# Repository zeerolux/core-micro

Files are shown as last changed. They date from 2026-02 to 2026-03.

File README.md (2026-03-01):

# Zeerolux Core-Micro

A lighting controller, control surface with 5 faders and 2 encoders, a USB DMX interface, an ARTNET node, and a standalone DMX generator. The Core-Micro system consists or 4 modules; the logic processor, the control surface, the DMX interface, and the redundant USB-C power supply. These modules are designed in a way that allows them to be iterated on separetly and allow for a limitless amount of configuration. How do you use Core-Micro? It depends on how YOU need to use it. Core-Micro can be used as a midi controller for On-PC lighting softwares, it can be used in a standalone mode where it acts like an all in one system for controlling stage lighting, and eventually it will be able to run in conjuction with other Zeerolux hardware and software as either the main controller or as a programming wing. It can also be used as an ARTNET node, this means that you can connect to it over the network and output DMX out its outputs.

### Defintions:
- DMX: Digital Multiplex is an RS485 based communication standard for controlling stage lights and equipment.
- ARTNET: DMX over IP
- On-PC: A standard term used by lighting consoles to describe control systems that require a laptop or PC to operate as opposed to all processing running on console.



### Why?
I decided to take on this project after I realised how incredibly expensive lighting consoles are. Out of curiosity, I wanted to see whether I could build my own console and what price it would turn out at. Another inspiration was my experience with the Avolites Quartz which to say the least was... frustrating, so naturally, I was fresh with ideas on what not to do.



## The Hardware
Core-Micro has four PCBs; one for each module. 

### Logic PCB:


The Logic PCB does a few main things:
- Connects to PC over USB
- Processes DMX signals and distrobutes them to DMX PCB(s)
- Runs ARTNET
- Interfaces with Surface PCB
All the main processing is powered by an RP2040 and the ethernet controller is a W5500.



### Control Surface PCB


This PCB's purpose is as follows:
- To have enough buttons to comfortably program lights
- To have enough faders for basic theatre applications
- To interface with the Logic board and passthrough control to PC applications or standalone mode.
Like the Logic PCB, the Control Surface is powered by an RP2040 and sends commands to other components via UART.



### Power PCB


Why do we need a separate PCB for power? Redundancy. In a live production environment, we cannot tolerate any power cuts or flaky USB connections. Therefore, I designed a board that has two inputs that can automatically be switched between if one cuts out. This allows for:
- Usage of independant power supplies for redundancy
- Automatic switch over to battery power during power cuts or brownouts
There is also a Superviser IC on this PCB in case I want to add that functionality in the future to other modules.



### DMX Interface PCB


This simple PCB converts the PIO DMX signal into RS485 signal that can be sent to DMX fixtures. This board also has both 3-pin and 5-pin XLR to ensure you can connect to any light.



## The Software

At this current moment, the software is a minimal version designed for testing DMX and ARTNET in a standalone mode. Here is the ideal list of software features I would like to implement:
- Standalone mode
- ARTNET node mode
- Midi Mode
- Custom serial driver for control via custom software

## BOM

## Bill of Materials (BOM)

| Item | Qty | Link / Supplier | List Price  | Actual  | Location | Shipping  |
|---|-----|---|---|---|---|---|
| Surface PCB | 5 | JLCPCB | 17.90 | 190.94 | JLCPCB | 33.14 |
| Surface PCB Assembly | 2 | JLCPCB | 39.89 | — | aliexpress | — |
| Logic PCB | 5 | JLCPCB | 4.00 | — | mouser | 20.00 |
| Logic PCB Assembly | 2 | JLCPCB | 48.14 | — | beekeeb | 15.64 |
| DMX PCB | 5 | JLCPCB | 4.00 | — | — | — |
| DMX PCB Assembly | 2 | JLCPCB | 18.58 | — | — | — |
| Power PCB | 5 | JLCPCB | 2.00 | — | — | — |
| Power PCB Assembly | 2 | JLCPCB | 43.29 | — | — | — |
| Encoders | 3 | Mouser | 5.07 | 5.07 | — | — |
| Faders | 5 | Mouser | 9.60 | 9.60 | — | — |
| USB B Socket | 1 | Mouser | 0.95 | 0.95 | — | — |
| Threaded Inserts M3 | 100 | AliExpress | 5.00 | 5.00 | — | — |
| Threaded Inserts M2 | 100 | AliExpress | 5.00 | 5.00 | — | — |
| Screws M3 | 50  | AliExpress | 3.00 | 3.00 | — | — |
| Screws M2 | 50  | AliExpress | 3.00 | 3.00 | — | — |
| Key Switches | 50  | Beekeeb | 49.00 | 49.00 | — | — |
| Neutrik 3 Pin XLR | 2 | Mouser | 5.64 | 5.64 | — | — |
| Neutrik 5 Pin XLR | 2 | Mouser | 7.74 | 7.74 | — | — |
| Shipping (overall products) | — | — | 68.78 | — | — | — |
| **Total Cost** | — | — | **284.94** | — | — | — |

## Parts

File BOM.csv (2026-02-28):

Item | Quantity | Link | List Price | Actual | location | shipping cost
Surface PCB | 5 | JLCPCB | 17.9 | 190.94 | JLCPCB | 33.14
Surface PCB Assembly | 2 | JLCPCB | 39.89 |  | aliexpress
Logic PCB | 5 | JLCPCB | 4 |  | mouser | 20
Logic PCB Assembly | 2 | JLCPCB | 48.14 |  | beekeeb | 15.64
DMX PCB | 5 | JLCPCB | 4
DMX PCB Assembly | 2 | JLCPCB | 18.58
Power PCB | 5 | JLCPCB | 2
Power PCB Assembly | 2 | JLCPCB | 43.29
Encoders | 3 | https://au.mouser.com/ProductDetail/Bourns/PEC12R-4220F-S0024?qs=Zq5ylnUbLm7u%2FuPQvUoR4Q%3D%3D | 5.07 | 5.07
Faders | 5 | https://au.mouser.com/ProductDetail/Bourns/PTA6043-2015DPB103?qs=U%2FacTlguYxYM6XeKwIsltg%3D%3D | 9.6 | 9.6
USB B socket | 1 | https://au.mouser.com/ProductDetail/Harwin/M701-330442?qs=x6EjVpvqMVOIQFAB0splYQ%3D%3D | 0.95 | 0.95
Threaded inserts m3 | 100 | https://www.aliexpress.com/item/1005008897571758.html | 5 | 5
Threaded inserts m2 | 100 | https://www.aliexpress.com/item/1005008897571758.html | 5 | 5
Screws m3 | 50 | https://www.aliexpress.com/item/1005007593838226.html | 3 | 3
Screws m2 | 50 | https://www.aliexpress.com/item/1005007593838226.html | 3 | 3
Key Switches | 50 | https://shop.beekeeb.com/products/sunset-choc-key-switch | 49 | 49
Neutrix 3 pin XLR | 2 | https://au.mouser.com/ProductDetail/Neutrik/NC3FAH-0?qs=JfNPhaIww3KVRIFFDchtUA%3D%3D | 5.64 | 5.64
Neutrix 5 pin XLR | 2 | https://au.mouser.com/ProductDetail/Neutrik/NC5FAH-0?qs=6LylQoPC2St0w7oAc5hVvw%3D%3D | 7.74 | 7.74
Shipping (over all products) | n/a | n/a | 68.78
Total Cost |  |  | 284.94

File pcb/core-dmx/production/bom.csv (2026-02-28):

Designator | Footprint | Quantity | Value | LCSC Part #
_3, _2, |  | 3
J3, J4 | TerminalBlock_Xinya_XY308-2.54-2P_1x02_P2.54mm_Horizontal | 2 | Screw_Terminal_01x02
U1 | SOIC-8_3.9x4.9mm_P1.27mm | 1 | MAX485E

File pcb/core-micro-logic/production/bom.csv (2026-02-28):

Designator | Footprint | Quantity | Value | LCSC Part #
C1, C14, C5, C8 | 0402 | 4 | 1uF | C52923
C10, C9 | 0402 | 2 | 22pF | C1555
C11, C12, C17, C18, C19, C21, C22, C23, C24, C4 | 0402 | 10 | 100nF | C1525
C13 | 0402 | 1 | 10uF | C15525
C15, C16, C3 | 0402 | 3 | 100nF
C2, C6, C7 | 0402 | 3 | 1uF
C20 | 0402 | 1 | 1nF
D1 | 0201 | 1 | LED
FB1, FB2 | 0603 | 2 | FerriteBead
J1, J2, J3, J4, J5, J6 | TerminalBlock_Xinya_XY308-2.54-2P_1x02_P2.54mm_Horizontal | 6 | Screw_Terminal_01x02
J7 | USB_C_Receptacle_HRO_TYPE-C-31-M-12 | 1 | USB_C_Receptacle_USB2.0 | C165948
J9 | HANRUN_HR911105A | 1 | HR911105A
R1, R5 | 0402 | 2 | R
R10, R12, R9 | 0402 | 3 | 10k
R11, R15 | 0402 | 2 | 1k | C11702
R13, R14, R8 | 0402 | 3 | 1k
R3, R4 | 0603 | 2 | 27R | C25190
R6, R7 | 0402 | 2 | 5k1 | C25905
U1 | QFN-56-1EP_7x7mm_P0.4mm_EP3.2x3.2mm_ThermalVias | 1 | RP2040 | C2040
U2 | SOIC127P790X216-8N | 1 | W25Q128JVS | C131025
U3 | SOT-23 | 1 | XC6206PxxxMR-Regulator_Linear | C5446
U4 | LQFP-48_7x7mm_P0.5mm | 1 | W5500
U5 | SOT-23-6 | 1 | USBLC6-2SC6 | C2827654
Y1 | Crystal_SMD_3225-4Pin_3.2x2.5mm | 1 | 12MHz | C9002

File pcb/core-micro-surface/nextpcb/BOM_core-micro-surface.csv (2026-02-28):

reference | value | footprint | MPN | manufacturer | Category | SKU | price | quantity
Brd1 | SSD1306 | 128x64OLED | SSD1306-220MT | LanTu Micro | Inductors | 1020534235 | 0.30966 | 1
C1,C10,C4,C3 | 1uF | C_0402_1005Metric | 0402ZD105MAT2A | Kyocera | Capacitors | - | - | 4
C6,C5 | 22pF | C_0402_1005Metric | 0402ZA220JAT2A | Kyocera | Ceramic Capacitors | - | - | 2
C9 | 10uF | C_0402_1005Metric | AMK105CBJ106MV-F | Taiyo Yuden | Ceramic Capacitors | - | - | 1
C11,C12,C15,C14,C13,C7,C17,C16,C2,C8 | 100nF | C_0402_1005Metric | 0402YD104ZAT2A | Kyocera | Capacitors | - | - | 10
D48,D53,D49,D52,D51 | SK6812 | LED_SK6812_PLCC4_5.0x5.0mm_P3.2mm | SK6812 | OPSCO OPTOELECTRONICS | LEDs | 1023055504 | 0.09185 | 5
D50,D23,D45,D3,D28,D11,D25,D12,D14,D46,D40,D17,D44,D8,D35,D37,D26,D2,D9,D27,D34,D22,D1,D42,D32,D29,D18,D38,D33,D43,D4,D41,D7,D21,D39,D30,D20,D36,D5,D15,D47,D6,D24,D19,D16,D31,D13,D10 | 1N4148W | D_SOD-123 | 1N4148W | TK | PIN二极管 | 2500413313 | 0.0036 | 48
F1 | 500mA | Fuse_1206_3216Metric | ILB1206ER310V | Vishay | Ferrite Beads and Chips | - | - | 1
J1 | SWD | PinSocket_1x05_P2.54mm_Vertical | 640456-5 | TE Connectivity (Tyco Electronics) | Wire-to-Board Connectors | 2500330467 | 0.18468 | 1
J2 | AudioPlug2 | Jack_3.5mm_CUI_SJ-3523-SMT_Horizontal | SJ-3523-SMT | CUI | Cables and Wire | - | - | 1
J3 | USB_B | USB_B_TE_5787834_Vertical | 5787834-1 | TE Connectivity (Tyco Electronics) | DVI / HDMI Connectors | 2500417221 | 1.05392 | 1
J4 | Screw_Terminal_01x04 | TerminalBlock_Xinya_XY308-2.54-4P_1x04_P2.54mm_Horizontal | XY308-2.54-4P | XINLAIYA | Terminal Blocks | 1008509280 | 0.38994 | 1
R3,R2 | 27R | R_0603_1608Metric | RK73B1JTTD270J | KOA | Chip SMD Resistors | - | - | 2
R5,R4,R1 | 1k | R_0402_1005Metric | MCR01MRTF1001 | Rohm | Chip SMD Resistors | - | - | 3
R7,R6 | 4.7k | R_0402_1005Metric | MCR01MZPF4701 | Rohm | Chip SMD Resistors | - | - | 2
RV3,RV4,RV2,RV5,RV1 | R_Potentiometer | POT_PTA6043 | PTA6043-2010CIB503 | Bourns | Potentiometers | - | - | 5
SW21 | SW_Push | PinSocket_1x02_P2.54mm_Vertical | 87220-2 | TE Connectivity (Tyco Electronics) | Headers | - | - | 1
SW43,SW18,SW3,SW4,SW17,SW42,SW34,SW13,SW38,SW8,SW9,SW30,SW5,SW16,SW35,SW45,SW40,SW39,SW2,SW31,SW23,SW11,SW27,SW24,SW32,SW37,SW29,SW25,SW22,SW33,SW12,SW7,SW14,SW10,SW28,SW15,SW6,SW44,SW41,SW36,SW26,SW20,SW1,SW19 | SW_Push | SW_Hotswap_Kailh_Choc_V1V2_1.00u | CPG135001S30 | Kailh | Universal | - | - | 44
SW46,SW48,SW47 | RotaryEncoder_Switch | XDCR_PEC12R-4220F-S0024 | PEC12R-4220F-S0024 | Bourns | Encoders | 1028163618 | 1.81583 | 3
U1 | RP2040 | QFN-56-1EP_7x7mm_P0.4mm_EP3.2x3.2mm | RP2040 | Raspberry Pi | Microcontrollers | 2500395072 | 0.89857 | 1
U2 | W25Q128JVS | SOIC127P790X216-8N | 25YD80-R | Vishay | Capacitors | - | - | 1
U3 | XC6206PxxxMR-Regulator_Linear | SOT-23 | MCP73833-AMI/UN | Microchip Technology | Battery Management | - | - | 1
U4 | USBLC6-2SC6 | SOT-23-6 | USBLC6-2SC6 | STMicroelectronics | TVS Diodes | 2500337959 | 0.02748 | 1
U5 | ADS1115IDGS | TSSOP-10_3x3mm_P0.5mm | ADS1115IDGST | Texas Instruments (TI) | Latches and Flip Flops | 2300141696 | 6.39041 | 1
Y1 | 12MHz | Crystal_SMD_3225-4Pin_3.2x2.5mm | AWSCR-12.00CV-T | Abracon | Resonators | 1039126278 | 0.27244 | 1

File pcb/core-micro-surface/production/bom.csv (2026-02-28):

Designator | Footprint | Quantity | Value | LCSC Part #
_6, _5, _4, _3, _2, |  | 6
BRD1 | 128x64OLED | 1 | SSD1306
C1, C10, C3, C4 | 0402 | 4 | 1uF | C52923
C11, C12, C13, C14, C15, C16, C17, C2, C7, C8 | 0402 | 10 | 100nF | C1525
C5, C6 | 0402 | 2 | 22pF | C1555
C9 | 0402 | 1 | 10uF | C15525
D1, D10, D11, D12, D13, D14, D15, D16, D17, D18, D19, D2, D20, D21, D22, D23, D24, D25, D26, D27, D28, D29, D3, D30, D31, D32, D33, D34, D35, D36, D37, D38, D39, D4, D40, D41, D42, D43, D44, D45, D46, D47, D5, D50, D6, D7, D8, D9 | D_SOD-123 | 48 | 1N4148W
D48, D49, D51, D52, D53 | LED_SK6812_PLCC4_5.0x5.0mm_P3.2mm | 5 | SK6812
F1 | 1206 | 1 | 500mA | C70076
J2 | Jack_3.5mm_CUI_SJ-3523-SMT_Horizontal | 1 | AudioPlug2
J3 | USB_B_TE_5787834_Vertical | 1 | USB_B
J4 | TerminalBlock_Xinya_XY308-2.54-4P_1x04_P2.54mm_Horizontal | 1 | Screw_Terminal_01x04
R1, R4, R5 | 0402 | 3 | 1k | C11702
R2, R3 | 0603 | 2 | 27R | C25190
R6, R7 | 0402 | 2 | 4.7k
RV1, RV2, RV3, RV4, RV5 | POT_PTA6043 | 5 | R_Potentiometer
SW1, SW10, SW11, SW12, SW13, SW14, SW15, SW16, SW17, SW18, SW19, SW2, SW20, SW22, SW23, SW24, SW25, SW26, SW27, SW28, SW29, SW3, SW30, SW31, SW32, SW33, SW34, SW35, SW36, SW37, SW38, SW39, SW4, SW40, SW41, SW42, SW43, SW44, SW45, SW5, SW6, SW7, SW8, SW9 | SW_Kailh_Choc_V1_1.00u | 44 | SW_Push
SW46, SW47, SW48 | XDCR_PEC12R-4220F-S0024 | 3 | RotaryEncoder_Switch
U1 | QFN-56-1EP_7x7mm_P0.4mm_EP3.2x3.2mm | 1 | RP2040 | C2040
U2 | SOIC127P790X216-8N | 1 | W25Q128JVS | C131025
U3 | SOT-23 | 1 | XC6206PxxxMR-Regulator_Linear | C5446
U4 | SOT-23-6 | 1 | USBLC6-2SC6 | C2827654
U5 | TSSOP-10_3x3mm_P0.5mm | 1 | ADS1115IDGS
Y1 | Crystal_SMD_3225-4Pin_3.2x2.5mm | 1 | 12MHz | C9002

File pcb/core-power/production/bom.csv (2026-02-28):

Designator | Footprint | Quantity | Value | LCSC Part #
 |  | 1
C1 | 0603 | 1 | 22nF
C2, C3 | 0603 | 2 | 10uF
C4 | 0603 | 1 | 22uF
C5, C6 | 0603 | 2 | 100nF
J1, J2 | HRO_TYPE-C-31-M-12 | 2 | USB_C_Receptacle_USB2.0_16P
J3 | TerminalBlock_Xinya_XY308-2.54-5P_1x05_P2.54mm_Horizontal | 1 | Screw_Terminal_01x05
R1, R2, R3 | RES_VISHAY_WSLP2512_C_VIS | 3 | WSLP2512R0100FEA
R5 | 0402 | 1 | 5.5k
U1, U2, U3 | VSSOP-10_3x3mm_P0.5mm | 3 | INA226
U4, U5 | Texas_X2QFN-12_1.6x1.6mm_P0.4mm | 2 | TUSB320
U6 | SOIC8-N_MC_MCH | 1 | MCP130T-315I/SN
U7 | IC_TPS2121RUXR | 1 | TPS2121RUXR

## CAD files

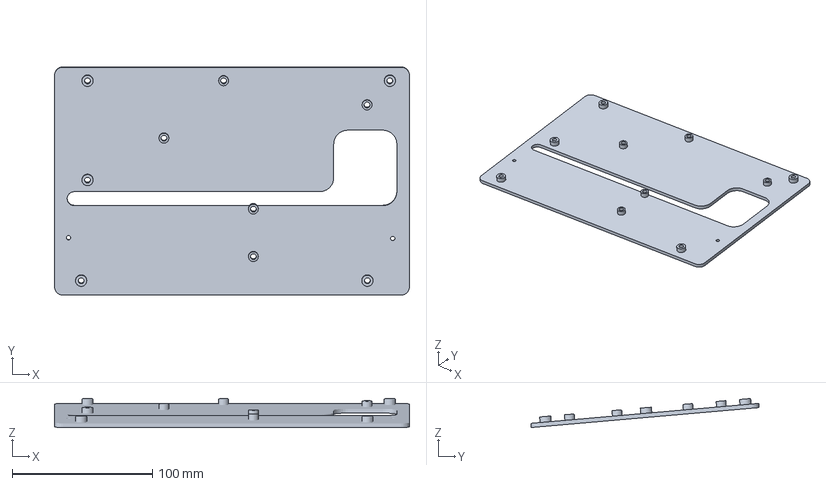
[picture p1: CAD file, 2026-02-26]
cad/Top.3mf
253.0 x 162.6 x 20.7 mm

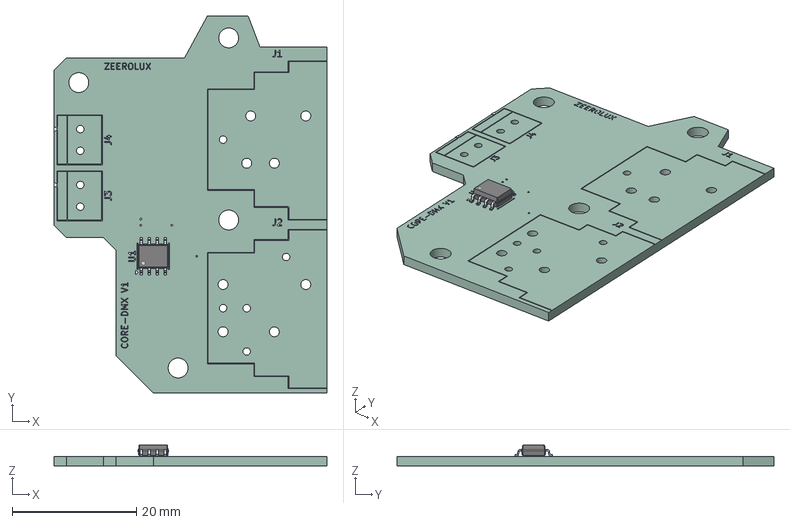
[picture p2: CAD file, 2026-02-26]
pcb/core-dmx/core-dmx.step
44.0 x 60.7 x 3.34 mm
SOIC-8_3.9x4.9mm_P1.27mm
core-dmx_silkscreen
core-dmx_PCB

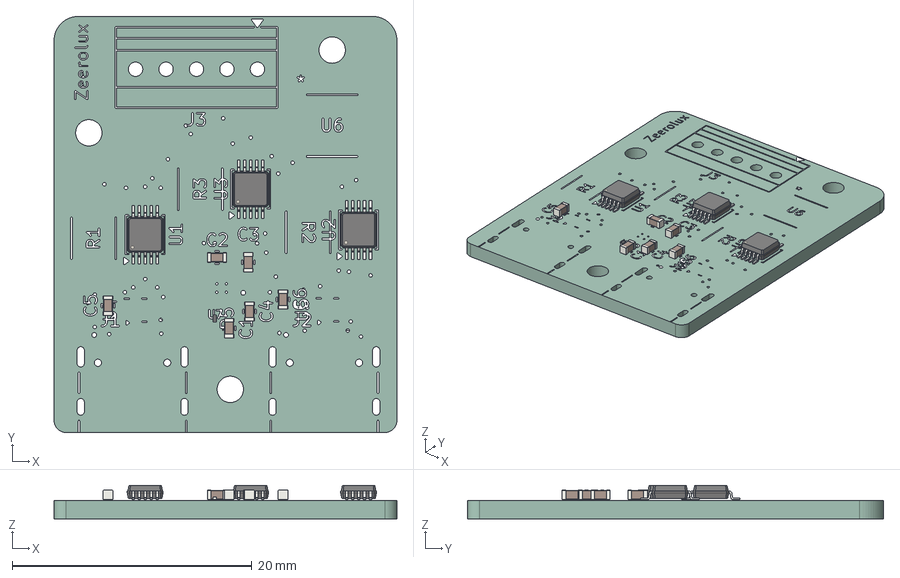
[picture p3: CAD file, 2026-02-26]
pcb/core-power/core-power.step
28.6 x 34.7 x 2.87 mm
C_0603_1608Metric x 6
VSSOP-10_3x3mm_P0.5mm x 3
R_0201_0603Metric
core-power_silkscreen x 2
core-power_PCB

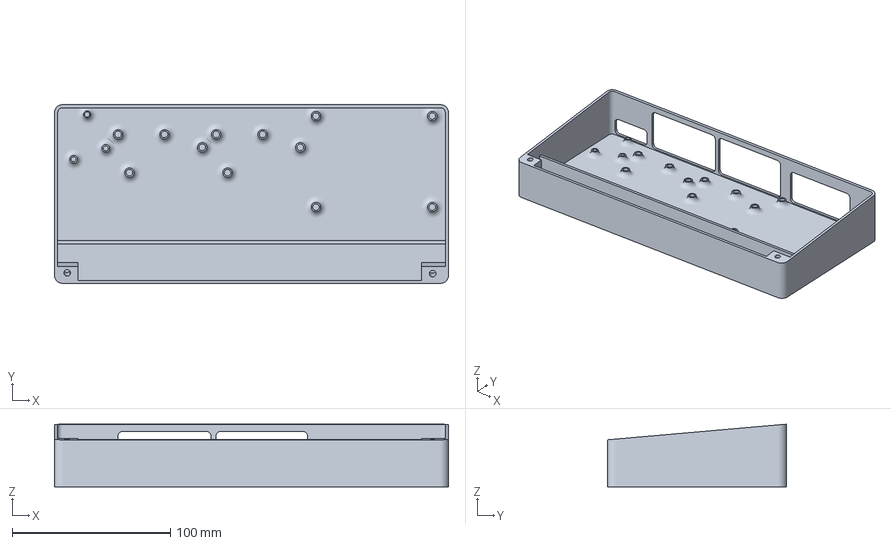
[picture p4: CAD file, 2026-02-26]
cad/Base.3mf
249.0 x 113.0 x 39.6 mm

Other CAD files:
cad/Base.f3d
cad/Top.f3d

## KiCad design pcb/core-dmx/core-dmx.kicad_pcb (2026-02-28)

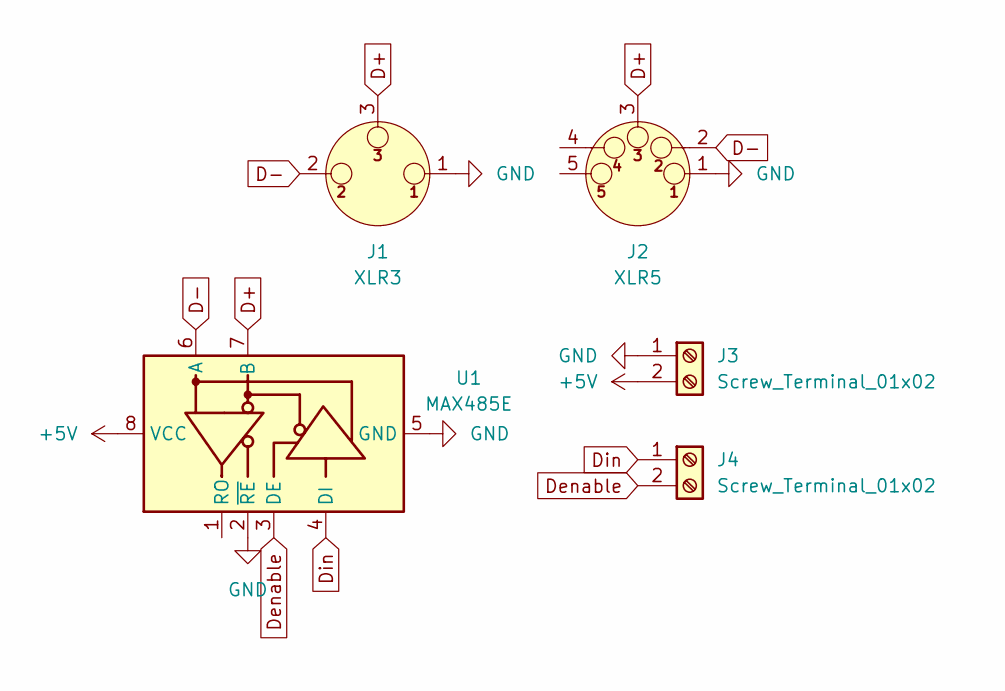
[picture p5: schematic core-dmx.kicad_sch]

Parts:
J1: XLR3; Jack_XLR_Neutrik_NC3FAH-0_Horizontal
J2: XLR5; Jack_XLR_Neutrik_NC5FAH-0_Horizontal
J3, J4: Screw_Terminal_01x02; TerminalBlock_Xinya_XY308-2.54-2P_1x02_P2.54mm_Horizontal
U1: MAX485E; SOIC-8_3.9x4.9mm_P1.27mm

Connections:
+5V: J3.2, U1.8 (VCC)
D+: J1.3, J2.3, U1.7 (B)
D-: J1.2, J2.2, U1.6 (A)
Denable: J4.2, U1.3 (DE)
Din: J4.1, U1.4 (DI)
GND: J1.1, J2.1, J3.1, U1.2 (~RE), U1.5 (GND)

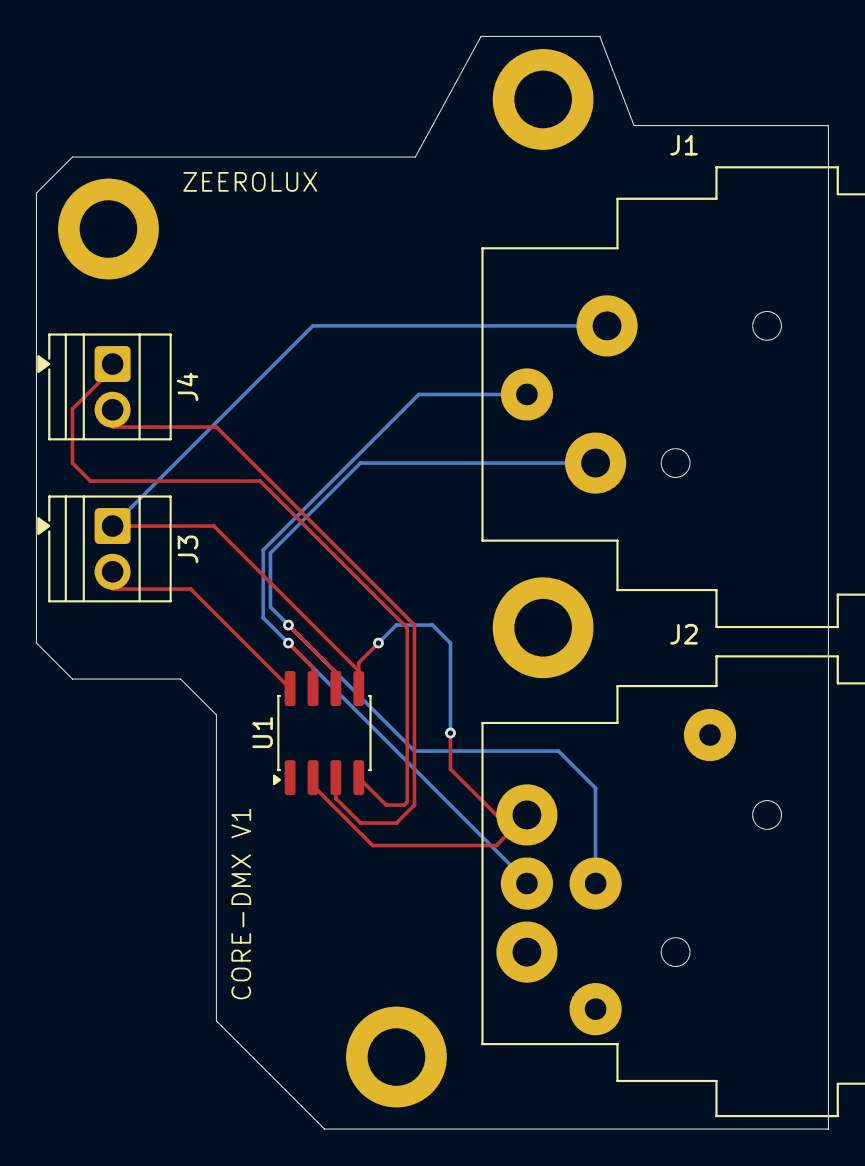
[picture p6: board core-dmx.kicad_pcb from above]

Board: 2 copper layers, 44.0 x 60.7 mm, 5 parts (0 on the bottom side), 6 nets.

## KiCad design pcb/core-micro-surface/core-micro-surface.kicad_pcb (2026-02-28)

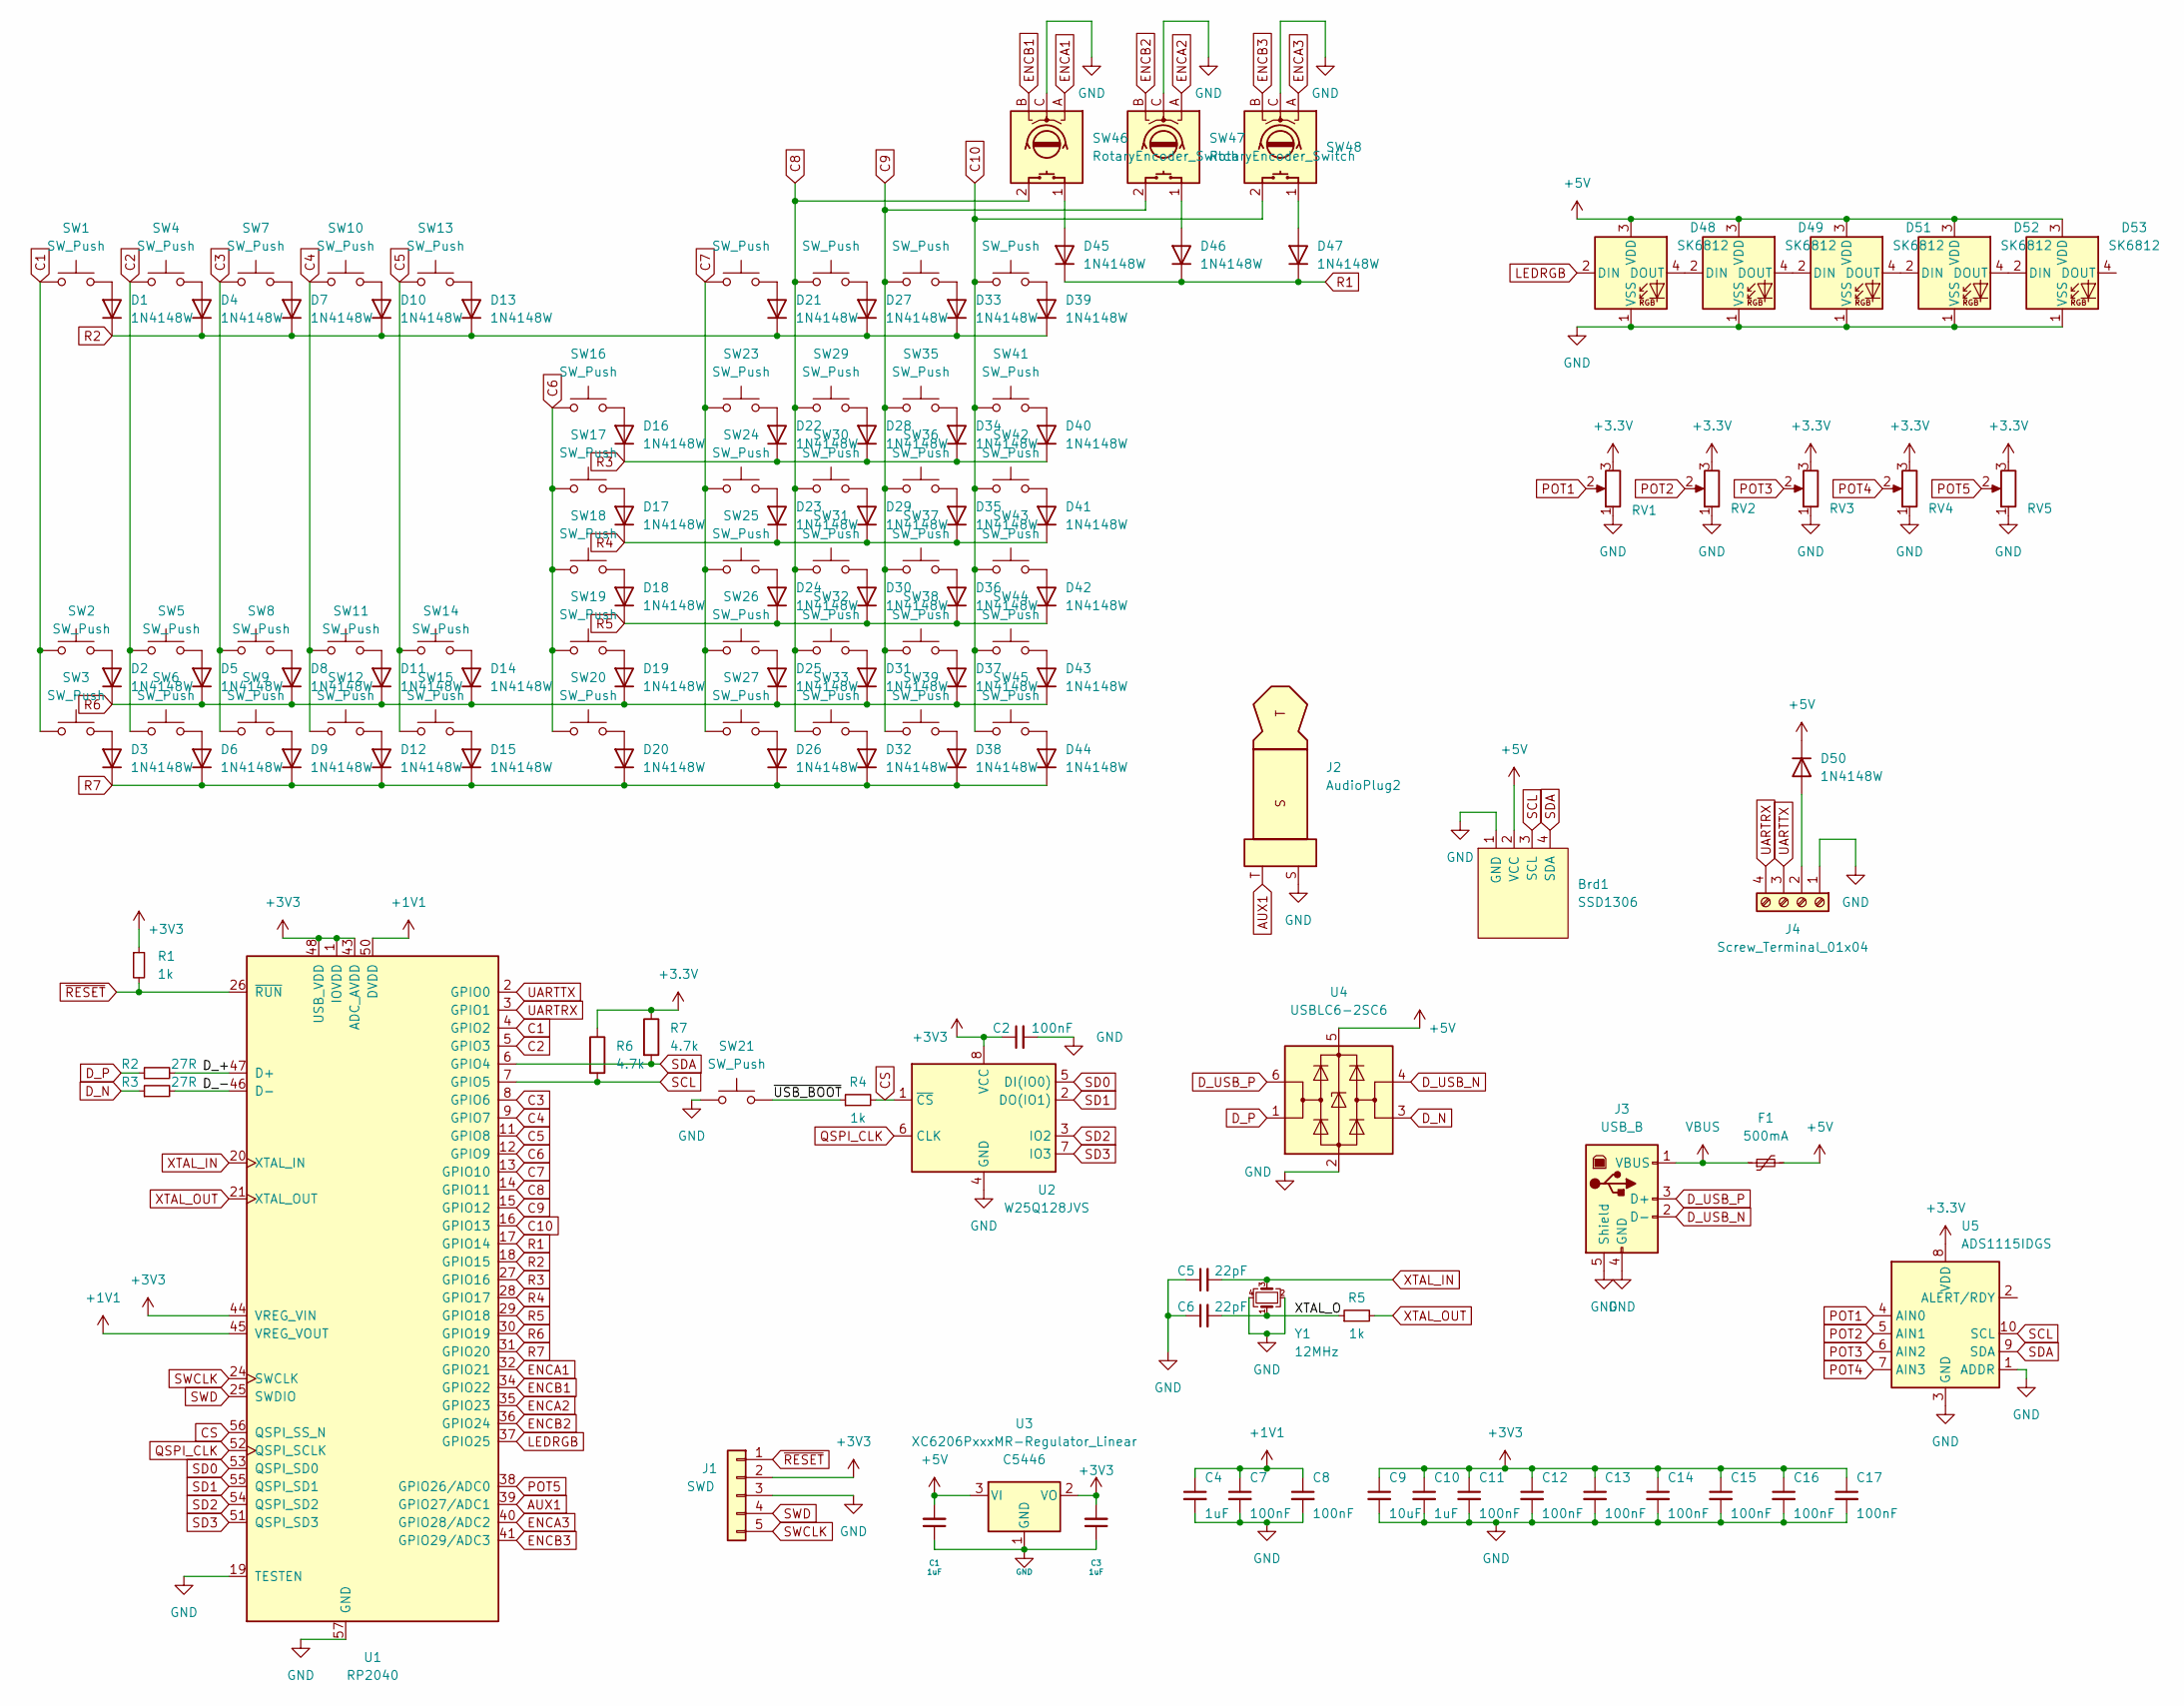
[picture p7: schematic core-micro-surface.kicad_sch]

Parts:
Brd1: SSD1306; 128x64OLED
C1, C3, C4, C10: 1uF; C_0402_1005Metric; LCSC C52923
C2, C7, C8, C11, C12, C13, C14, C15, C16, C17: 100nF; C_0402_1005Metric; LCSC C1525
C5, C6: 22pF; C_0402_1005Metric; LCSC C1555
C9: 10uF; C_0402_1005Metric; LCSC C15525
D1, D2, D3, D4, D5, D6, D7, D8, D9, D10, D11, D12, D13, D14, D15, D16, D17, D18, D19, D20, D21, D22, D23, D24, D25, D26, D27, D28, D29, D30, D31, D32, D33, D34, D35, D36, D37, D38, D39, D40, D41, D42, D43, D44, D45, D46, D47, D50: 1N4148W; D_SOD-123
D48, D49, D51, D52, D53: SK6812; LED_SK6812_PLCC4_5.0x5.0mm_P3.2mm
F1: 500mA; Fuse_1206_3216Metric; LCSC C70076
J1: SWD; PinSocket_1x05_P2.54mm_Vertical
J2: AudioPlug2; Jack_3.5mm_CUI_SJ-3523-SMT_Horizontal
J3: USB_B; USB_B_TE_5787834_Vertical
J4: Screw_Terminal_01x04; TerminalBlock_Xinya_XY308-2.54-4P_1x04_P2.54mm_Horizontal
R1, R4, R5: 1k; R_0402_1005Metric; LCSC C11702
R2, R3: 27R; R_0603_1608Metric; LCSC C25190
R6, R7: 4.7k; R_0402_1005Metric
RV1, RV2, RV3, RV4, RV5: R_Potentiometer; POT_PTA6043
SW1, SW2, SW3, SW4, SW5, SW6, SW7, SW8, SW9, SW10, SW11, SW12, SW13, SW14, SW15, SW16, SW17, SW18, SW19, SW20, SW22, SW23, SW24, SW25, SW26, SW27, SW28, SW29, SW30, SW31, SW32, SW33, SW34, SW35, SW36, SW37, SW38, SW39, SW40, SW41, SW42, SW43, SW44, SW45: SW_Push; SW_Hotswap_Kailh_Choc_V1V2_1.00u
SW21: SW_Push; PinSocket_1x02_P2.54mm_Vertical
SW46, SW47, SW48: RotaryEncoder_Switch; XDCR_PEC12R-4220F-S0024
U1: RP2040; QFN-56-1EP_7x7mm_P0.4mm_EP3.2x3.2mm; LCSC C2040
U2: W25Q128JVS; SOIC127P790X216-8N; LCSC C131025
U3: XC6206PxxxMR-Regulator_Linear; SOT-23; LCSC C5446
U4: USBLC6-2SC6; SOT-23-6; LCSC C2827654
U5: ADS1115IDGS; TSSOP-10_3x3mm_P0.5mm
Y1: 12MHz; Crystal_SMD_3225-4Pin_3.2x2.5mm; LCSC C9002

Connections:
+1V1: C4.1, C7.1, C8.1, U1.23 (DVDD), U1.45 (VREG_VOUT), U1.50 (DVDD)
+5V: Brd1.2 (VCC), C1.2, D48.3 (VDD), D49.3 (VDD), D50.1 (K), D51.3 (VDD), D52.3 (VDD), D53.3 (VDD), F1.2, U3.3 (VI), U4.5 (VBUS)
/D_+: R2.2, U1.47 (D+)
/D_-: R3.2, U1.46 (D-)
/XTAL_O: C6.2, R5.1, Y1.1
/~USB_BOOT: R4.1, SW21.2
AUX1: J2.T, U1.39 (GPIO27/ADC1)
C1: SW1.1, SW2.1, SW3.1, U1.4 (GPIO2)
C2: SW4.1, SW5.1, SW6.1, U1.5 (GPIO3)
C3: SW7.1, SW8.1, SW9.1, U1.8 (GPIO6)
C4: SW10.1, SW11.1, SW12.1, U1.9 (GPIO7)
C5: SW13.1, SW14.1, SW15.1, U1.11 (GPIO8)
C6: SW16.1, SW17.1, SW18.1, SW19.1, SW20.1, U1.12 (GPIO9)
C7: SW22.1, SW23.1, SW24.1, SW25.1, SW26.1, SW27.1, U1.13 (GPIO10)
C8: SW28.1, SW29.1, SW30.1, SW31.1, SW32.1, SW33.1, SW46.2 (S2), U1.14 (GPIO11)
C9: SW34.1, SW35.1, SW36.1, SW37.1, SW38.1, SW39.1, SW47.2 (2S2), U1.15 (GPIO12)
C10: SW40.1, SW41.1, SW42.1, SW43.1, SW44.1, SW45.1, SW48.2 (S2), U1.16 (GPIO13)
CS: R4.2, U1.56 (QSPI_SS_N), U2.1 (~CS)
D_N: R3.1, U4.3 (I/O2)
D_P: R2.1, U4.1 (I/O1)
D_USB_N: J3.2 (D-), U4.4 (I/O2)
D_USB_P: J3.3 (D+), U4.6 (I/O1)
ENCA1: SW46.A, U1.32 (GPIO21)
ENCA2: SW47.A, U1.35 (GPIO23)
ENCA3: SW48.A, U1.40 (GPIO28/ADC2)
ENCB1: SW46.B, U1.34 (GPIO22)
ENCB2: SW47.B, U1.36 (GPIO24)
ENCB3: SW48.B, U1.41 (GPIO29/ADC3)
GND: Brd1.1 (GND), C1.1, C2.2, C3.1, C4.2, C5.1, C6.1, C7.2, C8.2, C9.2, C10.2, C11.2, C12.2, C13.2, C14.2, C15.2, C16.2, C17.2, D48.1 (VSS), D49.1 (VSS), D51.1 (VSS), D52.1 (VSS), D53.1 (VSS), J1.3, J2.S, J3.4 (GND), J3.5 (Shield), J4.1, RV1.1, RV2.1, RV3.1, RV4.1, RV5.1, SW21.1, SW46.C, SW47.C, SW48.C, U1.19 (TESTEN), U1.57 (GND), U2.4 (GND), U3.1 (GND), U4.2 (GND), U5.1 (ADDR), U5.3 (GND), Y1.2, Y1.4
LEDRGB: D48.2 (DIN), U1.37 (GPIO25)
unnamed: D1.2 (A), SW1.2
unnamed: D2.2 (A), SW2.2
unnamed: D3.2 (A), SW3.2
unnamed: D4.2 (A), SW4.2
unnamed: D5.2 (A), SW5.2
unnamed: D6.2 (A), SW6.2
unnamed: D7.2 (A), SW7.2
unnamed: D8.2 (A), SW8.2
unnamed: D9.2 (A), SW9.2
unnamed: D10.2 (A), SW10.2
unnamed: D11.2 (A), SW11.2
unnamed: D12.2 (A), SW12.2
unnamed: D13.2 (A), SW13.2
unnamed: D14.2 (A), SW14.2
unnamed: D15.2 (A), SW15.2
unnamed: D16.2 (A), SW16.2
unnamed: D17.2 (A), SW17.2
unnamed: D18.2 (A), SW18.2
unnamed: D19.2 (A), SW19.2
unnamed: D20.2 (A), SW20.2
unnamed: D21.2 (A), SW22.2
unnamed: D22.2 (A), SW23.2
unnamed: D23.2 (A), SW24.2
unnamed: D24.2 (A), SW25.2
unnamed: D25.2 (A), SW26.2
unnamed: D26.2 (A), SW27.2
unnamed: D27.2 (A), SW28.2
unnamed: D28.2 (A), SW29.2
unnamed: D29.2 (A), SW30.2
unnamed: D30.2 (A), SW31.2
unnamed: D31.2 (A), SW32.2
unnamed: D32.2 (A), SW33.2
unnamed: D33.2 (A), SW34.2
unnamed: D34.2 (A), SW35.2
unnamed: D35.2 (A), SW36.2
unnamed: D36.2 (A), SW37.2
unnamed: D37.2 (A), SW38.2
unnamed: D38.2 (A), SW39.2
unnamed: D39.2 (A), SW40.2
unnamed: D40.2 (A), SW41.2
unnamed: D41.2 (A), SW42.2
unnamed: D42.2 (A), SW43.2
unnamed: D43.2 (A), SW44.2
unnamed: D44.2 (A), SW45.2
unnamed: D45.2 (A), SW46.1 (S1)
unnamed: D46.2 (A), SW47.1 (S1)
unnamed: D47.2 (A), SW48.1 (S1)
unnamed: D48.4 (DOUT), D49.2 (DIN)
unnamed: D49.4 (DOUT), D51.2 (DIN)
unnamed: D50.2 (A), J4.2
unnamed: D51.4 (DOUT), D52.2 (DIN)
unnamed: D52.4 (DOUT), D53.2 (DIN)
POT1: RV1.2, U5.4 (AIN0)
POT2: RV2.2, U5.5 (AIN1)
POT3: RV3.2, U5.6 (AIN2)
POT4: RV4.2, U5.7 (AIN3)
POT5: RV5.2, U1.38 (GPIO26/ADC0)
QSPI_CLK: U1.52 (QSPI_SCLK), U2.6 (CLK)
R1: D45.1 (K), D46.1 (K), D47.1 (K), U1.17 (GPIO14)
R2: D1.1 (K), D4.1 (K), D7.1 (K), D10.1 (K), D13.1 (K), D21.1 (K), D27.1 (K), D33.1 (K), D39.1 (K), U1.18 (GPIO15)
R3: D16.1 (K), D22.1 (K), D28.1 (K), D34.1 (K), D40.1 (K), U1.27 (GPIO16)
R4: D17.1 (K), D23.1 (K), D29.1 (K), D35.1 (K), D41.1 (K), U1.28 (GPIO17)
R5: D18.1 (K), D24.1 (K), D30.1 (K), D36.1 (K), D42.1 (K), U1.29 (GPIO18)
R6: D2.1 (K), D5.1 (K), D8.1 (K), D11.1 (K), D14.1 (K), D19.1 (K), D25.1 (K), D31.1 (K), D37.1 (K), D43.1 (K), U1.30 (GPIO19)
R7: D3.1 (K), D6.1 (K), D9.1 (K), D12.1 (K), D15.1 (K), D20.1 (K), D26.1 (K), D32.1 (K), D38.1 (K), D44.1 (K), U1.31 (GPIO20)
SCL: Brd1.3 (SCL), R6.2, U1.7 (GPIO5), U5.10 (SCL)
SD0: U1.53 (QSPI_SD0), U2.5 (DI(IO0))
SD1: U1.55 (QSPI_SD1), U2.2 (DO(IO1))
SD2: U1.54 (QSPI_SD2), U2.3 (IO2)
SD3: U1.51 (QSPI_SD3), U2.7 (IO3)
SDA: Brd1.4 (SDA), R7.2, U1.6 (GPIO4), U5.9 (SDA)
SWCLK: J1.5, U1.24 (SWCLK)
SWD: J1.4, U1.25 (SWDIO)
UARTRX: J4.4, U1.3 (GPIO1)
UARTTX: J4.3, U1.2 (GPIO0)
VBUS: F1.1, J3.1 (VBUS)
XTAL_IN: C5.2, U1.20 (XTAL_IN), Y1.3
XTAL_OUT: R5.2, U1.21 (XTAL_OUT)
~RESET: J1.1, R1.2, U1.26 (~RUN)

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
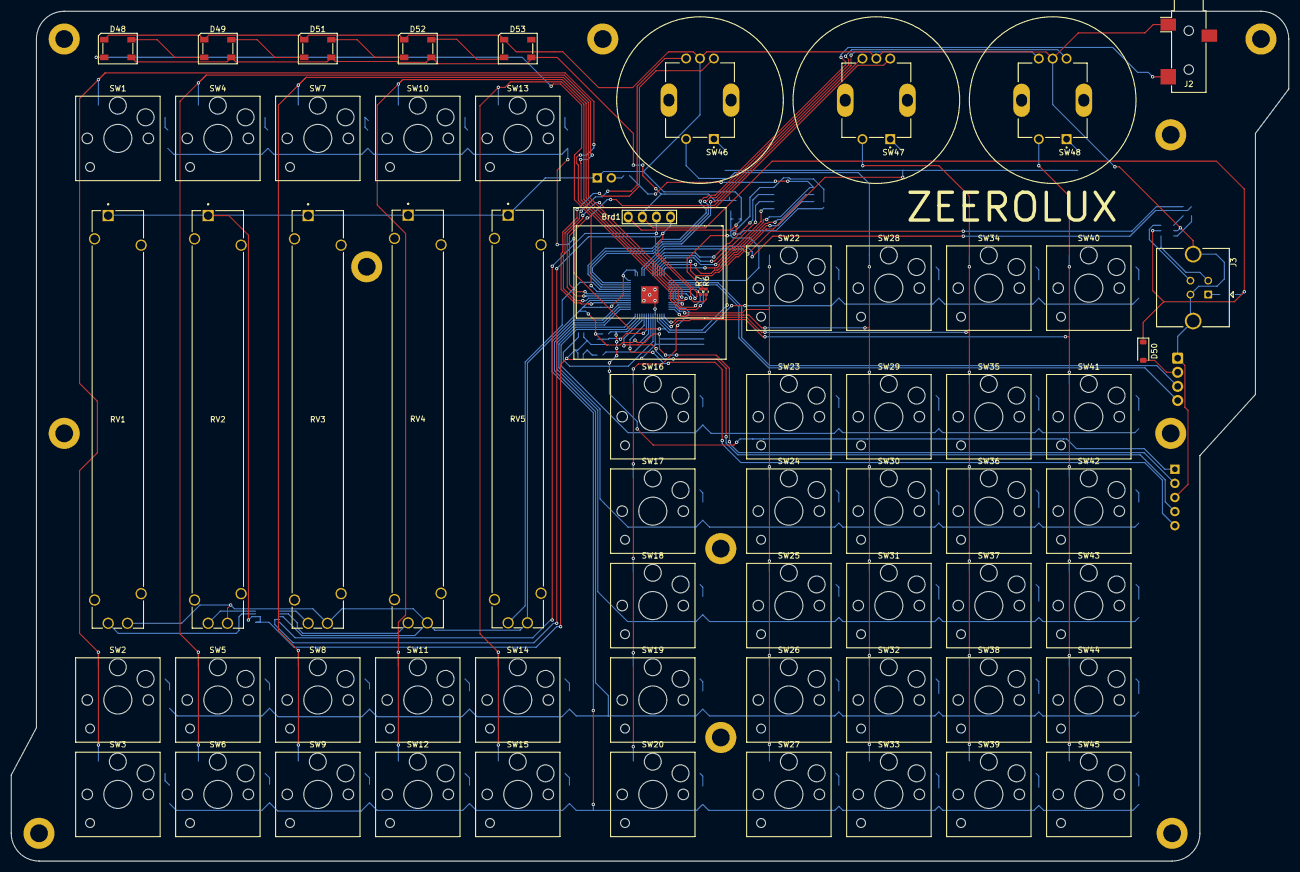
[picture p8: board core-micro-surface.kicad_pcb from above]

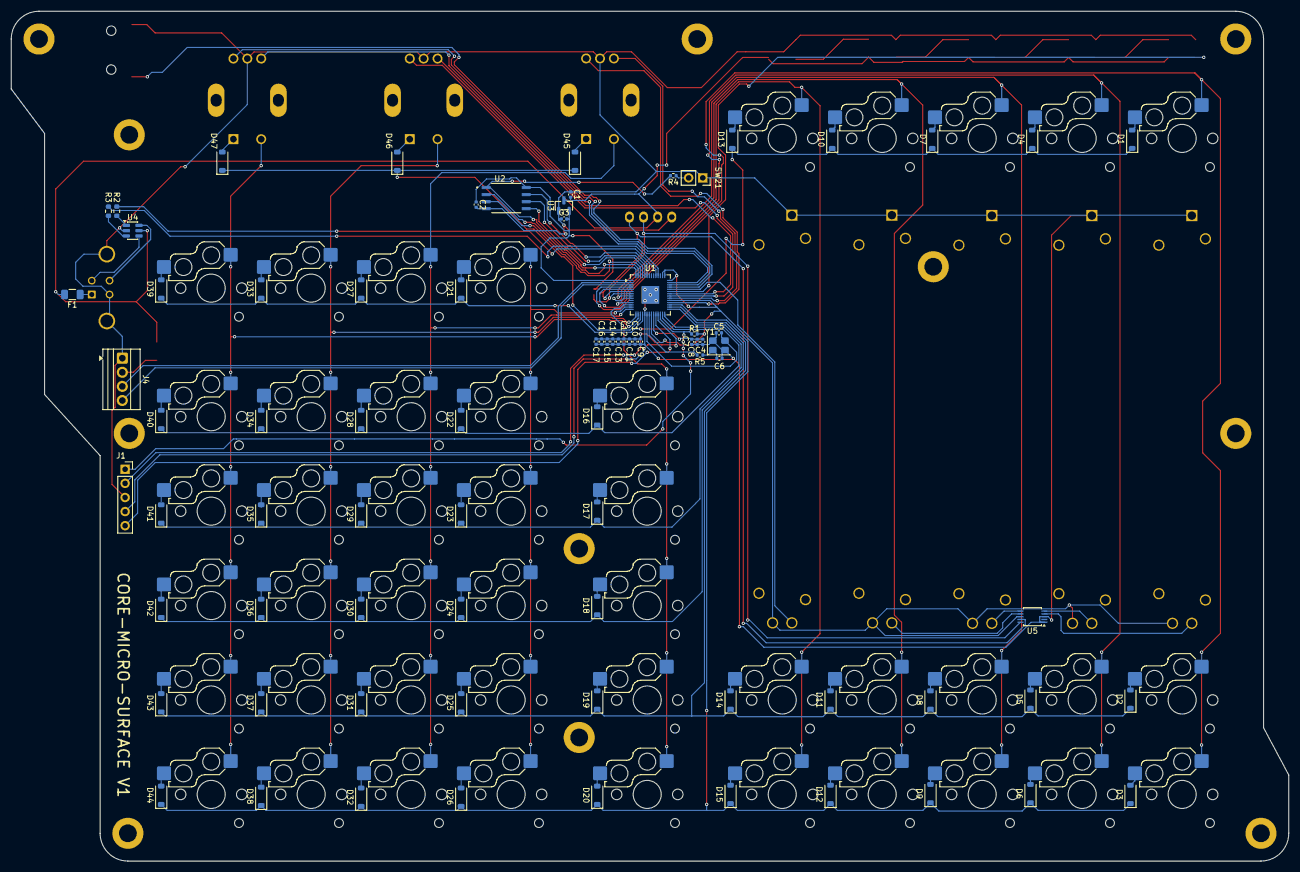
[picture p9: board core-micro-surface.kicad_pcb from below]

Board: 2 copper layers, 230.0 x 153.0 mm, 142 parts (79 on the bottom side), 111 nets.

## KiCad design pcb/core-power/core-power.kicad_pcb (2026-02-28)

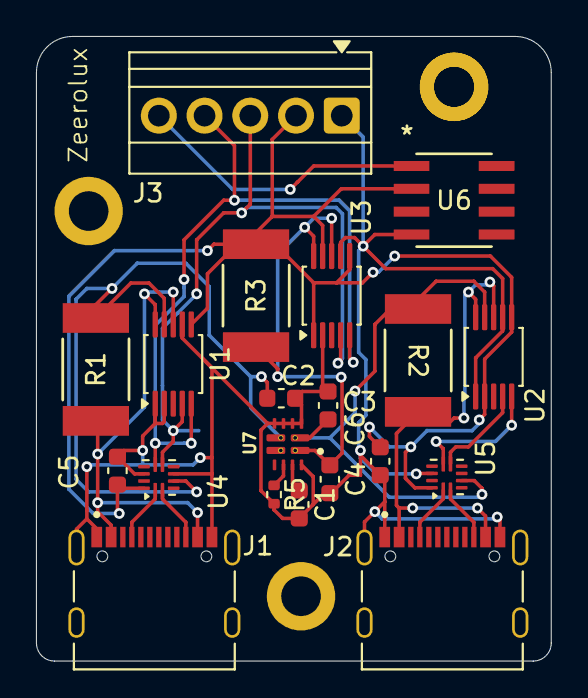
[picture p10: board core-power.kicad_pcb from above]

Board: 2 copper layers, 28.6 x 34.7 mm, 20 parts (0 on the bottom side), 16 nets.

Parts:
C1: 22nF; C_0603_1608Metric
C2, C3: 10uF; C_0603_1608Metric
C4: 22uF; C_0603_1608Metric
C5, C6: 100nF; C_0603_1608Metric
J1, J2: USB_C_Receptacle_USB2.0_16P; HRO_TYPE-C-31-M-12
J3: Screw_Terminal_01x05; TerminalBlock_Xinya_XY308-2.54-5P_1x05_P2.54mm_Horizontal
R1, R2, R3: WSLP2512R0100FEA; RES_VISHAY_WSLP2512_C_VIS
R5: 5.5k; R_0402_1005Metric
U1, U2, U3: INA226; VSSOP-10_3x3mm_P0.5mm
U4, U5: TUSB320; Texas_X2QFN-12_1.6x1.6mm_P0.4mm
U6: MCP130T-315I/SN; SOIC8-N_MC_MCH
U7: TPS2121RUXR; IC_TPS2121RUXR

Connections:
CC1-1: J1.A5 (CC1), U4.1 (CC1)
CC1-2: J2.A5 (CC1), U5.1 (CC1)
CC2-1: J1.B5 (CC2), U4.2 (CC2)
CC2-2: J2.B5 (CC2), U5.2 (CC2)
GND: C1.2, C2.2, C3.2, C4.2, C5.2, C6.2, J1.GND, J1.S1 (SHIELD), J2.A1_B12, J2.B1_A12, J2.S1 (SHIELD), J3.1, R5.2, U1.1 (A1), U1.2 (A0), U1.7 (GND), U2.1 (A1), U2.7 (GND), U3.2 (A0), U3.7 (GND), U4.5 (ADDR), U4.10 (GND), U5.10 (GND), U6.4 (VSS), U7.3 (CP2), U7.4 (OV2), U7.5 (OV1), U7.6 (PR1), U7.12 (GND)
J1V+: J1.A4_B9, R1.1, U1.8 (Vbus), U1.10 (Vin+)
J1V-: C2.1, R1.2, U1.9 (Vin-), U4.4 (VBUS_DET), U7.7 (IN1), U7.7_1 (IN1__1)
J2V+: R2.2, U2.8 (Vbus), U2.10 (Vin+)
J2V-: C3.1, R2.1, U2.9 (Vin-), U5.4 (VBUS_DET), U7.2 (IN2), U7.2_1 (IN2__1)
MUXV+: C4.1, R3.1, U3.8 (Vbus), U3.10 (Vin+), U7.1 (OUT), U7.1_1 (OUT__1), U7.8 (OUT__2), U7.8_1 (OUT__3)
MUXV-: C5.1, C6.1, J3.2, R3.2, U1.6 (VS), U2.2 (A0), U2.6 (VS), U3.1 (A1), U3.6 (VS), U3.9 (Vin-), U4.12 (VDD), U5.5 (ADDR), U5.12 (VDD), U6.2 (VDD)
unnamed: R5.1, U7.10 (ILIM)
unnamed: C1.1, U7.11 (SS)
RESET: J3.5, U6.1 (*RST)
SCL: J3.4, U1.5 (SCL), U2.5 (SCL), U3.5 (SCL), U4.8 (SCL/OUT2), U5.8 (SCL/OUT2)
SDA: J3.3, U1.4 (SDA), U2.4 (SDA), U3.4 (SDA), U4.7 (SDA/OUT1), U5.7 (SDA/OUT1)

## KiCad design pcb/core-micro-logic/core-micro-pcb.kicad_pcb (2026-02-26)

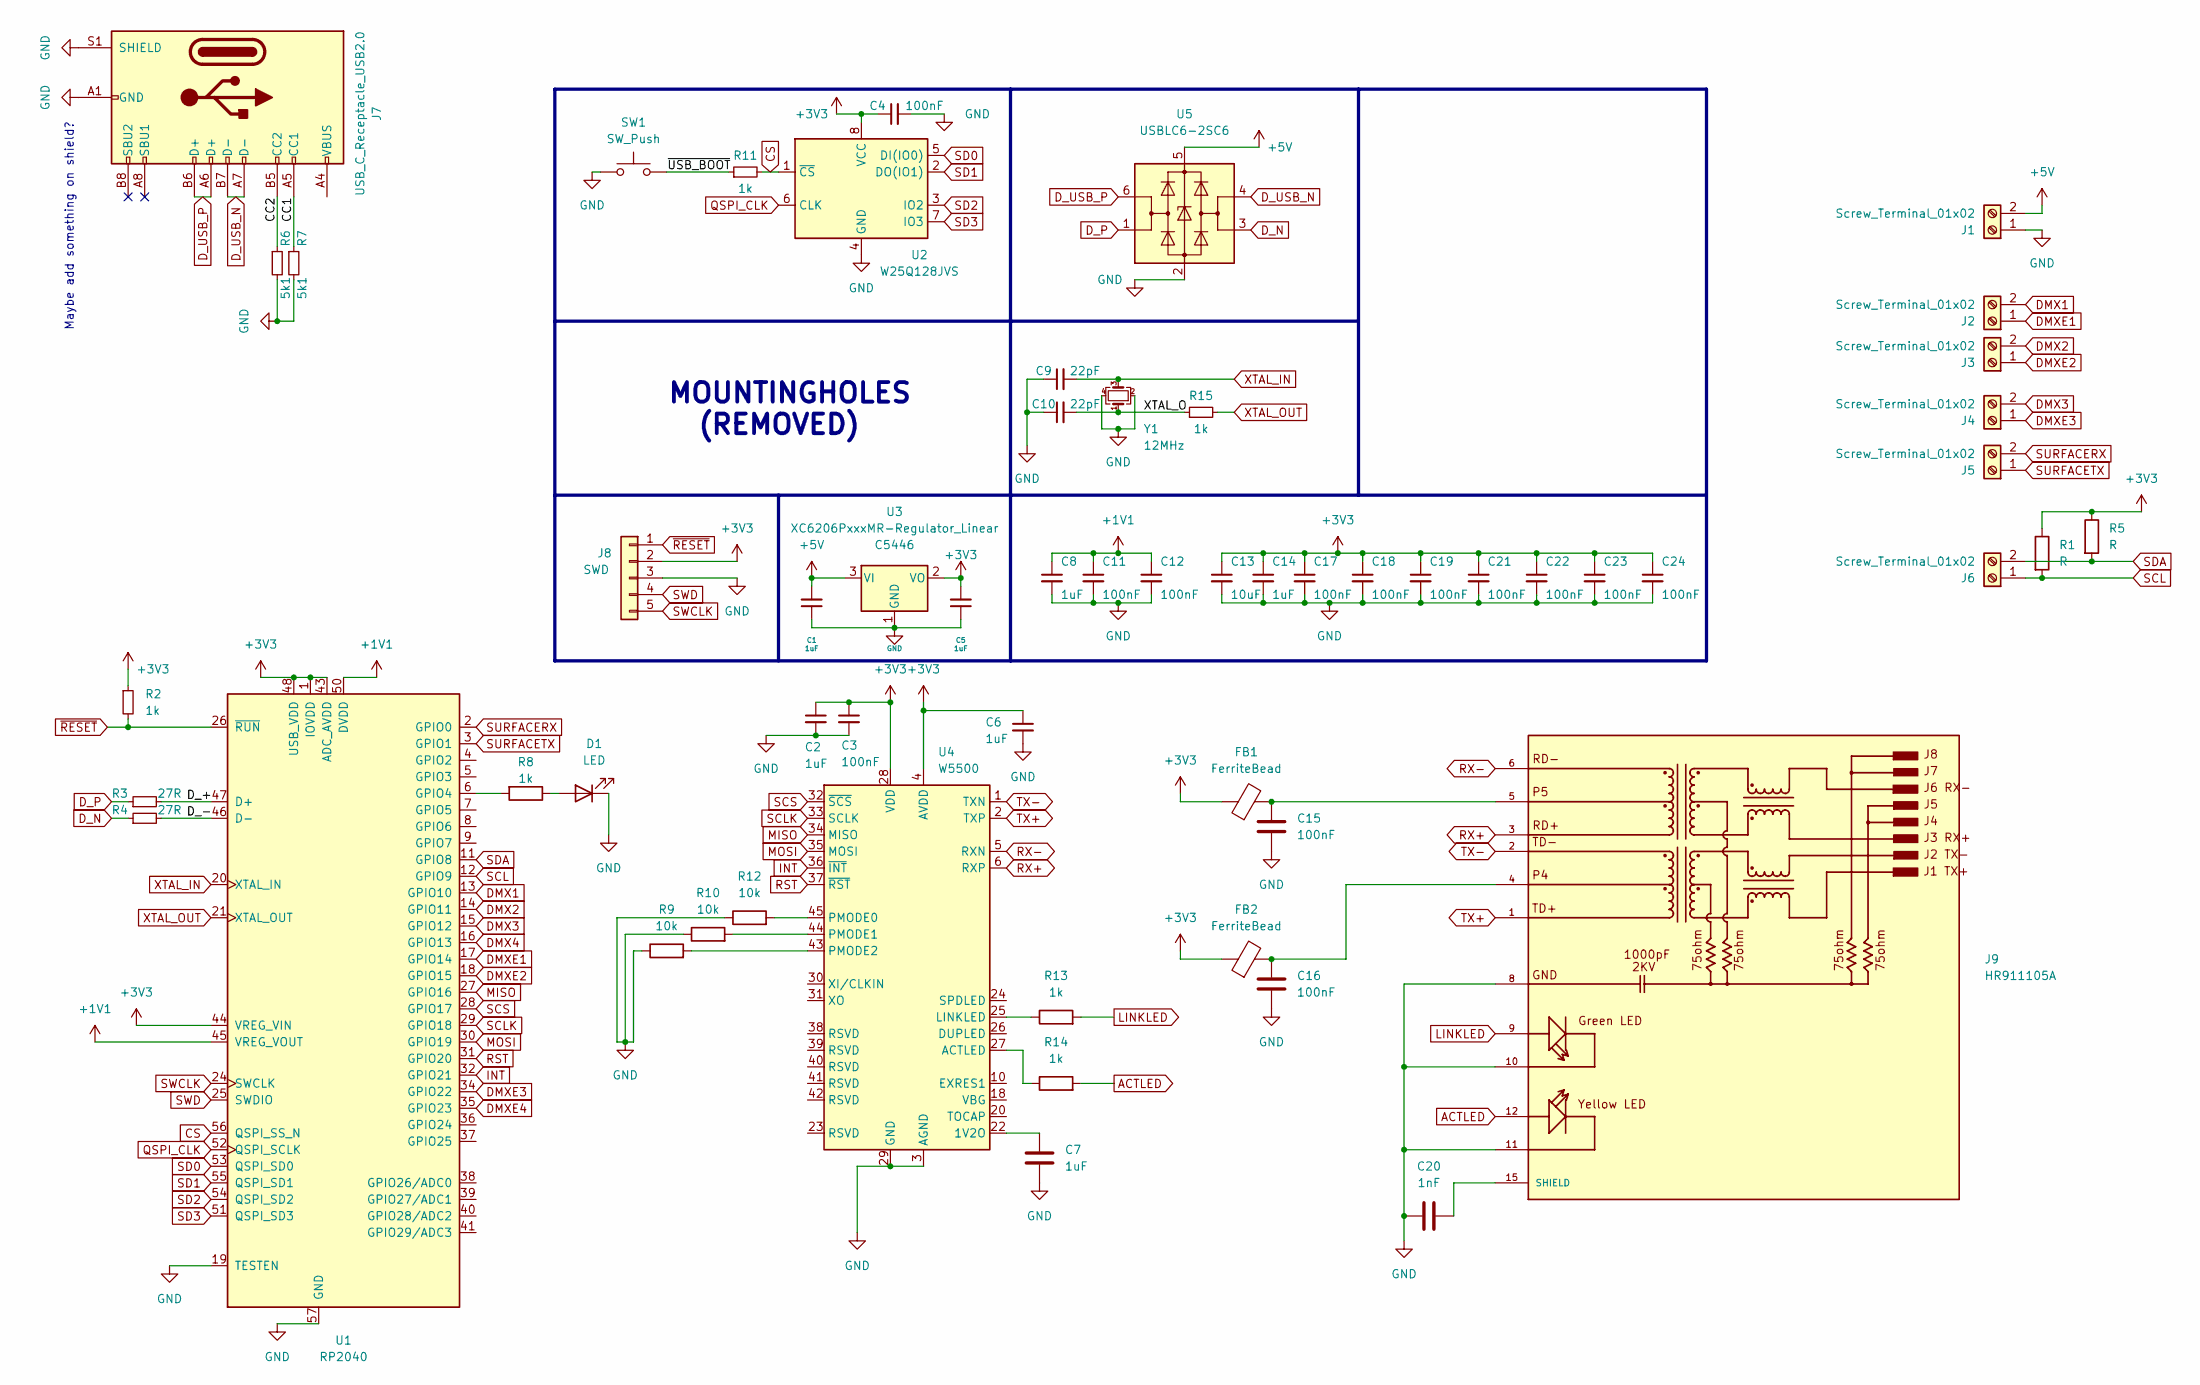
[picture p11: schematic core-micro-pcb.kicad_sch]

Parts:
C1, C5, C8, C14: 1uF; C_0402_1005Metric; LCSC C52923
C2, C6, C7: 1uF; C_0402_1005Metric
C3, C15, C16: 100nF; C_0402_1005Metric
C4, C11, C12, C17, C18, C19, C21, C22, C23, C24: 100nF; C_0402_1005Metric; LCSC C1525
C9, C10: 22pF; C_0402_1005Metric; LCSC C1555
C13: 10uF; C_0402_1005Metric; LCSC C15525
C20: 1nF; C_0402_1005Metric
D1: LED; LED_0201_0603Metric
FB1, FB2: FerriteBead; L_0603_1608Metric
J1, J2, J3, J4, J5, J6: Screw_Terminal_01x02; TerminalBlock_Xinya_XY308-2.54-2P_1x02_P2.54mm_Horizontal
J7: USB_C_Receptacle_USB2.0; HRO_TYPE-C-31-M-12; LCSC C165948
J8: SWD; PinSocket_1x05_P2.54mm_Vertical
J9: HR911105A; HANRUN_HR911105A; PARTREV A
R1, R5: R; R_0402_1005Metric
R2, R11, R15: 1k; R_0402_1005Metric; LCSC C11702
R3, R4: 27R; R_0603_1608Metric; LCSC C25190
R6, R7: 5k1; R_0402_1005Metric; LCSC C25905
R8, R13, R14: 1k; R_0402_1005Metric
R9, R10, R12: 10k; R_0402_1005Metric
SW1: SW_Push; PinSocket_1x02_P2.54mm_Vertical
U1: RP2040; QFN-56-1EP_7x7mm_P0.4mm_EP3.2x3.2mm_ThermalVias; LCSC C2040
U2: W25Q128JVS; SOIC127P790X216-8N; LCSC C131025
U3: XC6206PxxxMR-Regulator_Linear; SOT-23; LCSC C5446
U4: W5500; LQFP-48_7x7mm_P0.5mm
U5: USBLC6-2SC6; SOT-23-6; LCSC C2827654
Y1: 12MHz; Crystal_SMD_3225-4Pin_3.2x2.5mm; LCSC C9002

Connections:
+1V1: C8.1, C11.1, C12.1, U1.23 (DVDD), U1.45 (VREG_VOUT), U1.50 (DVDD)
+3V3: C2.1, C3.1, C4.1, C5.2, C6.1, C13.1, C14.1, C17.1, C18.1, C19.1, C21.1, C22.1, C23.1, C24.1, FB1.1, FB2.1, J8.2, R1.1, R2.1, R5.1, U1.1 (IOVDD), U1.10 (IOVDD), U1.22 (IOVDD), U1.33 (IOVDD), U1.42 (IOVDD), U1.43 (ADC_AVDD), U1.44 (VREG_VIN), U1.48 (USB_VDD), U1.49 (IOVDD), U2.8 (VCC), U3.2 (VO), U4.4 (AVDD), U4.8 (AVDD), U4.11 (AVDD), U4.15 (AVDD), U4.17 (AVDD), U4.21 (AVDD), U4.28 (VDD)
+5V: C1.2, J1.2, U3.3 (VI), U5.5 (VBUS)
/CC1: J7.A5 (CC1), R7.1
/CC2: J7.B5 (CC2), R6.1
/D_+: R3.2, U1.47 (D+)
/D_-: R4.2, U1.46 (D-)
/XTAL_O: C10.2, R15.1, Y1.1
/~USB_BOOT: R11.1, SW1.2
ACTLED: J9.12, R14.2
CS: R11.2, U1.56 (QSPI_SS_N), U2.1 (~CS)
DMX1: J2.2, U1.13 (GPIO10)
DMX2: J3.2, U1.14 (GPIO11)
DMX3: J4.2, U1.15 (GPIO12)
DMX4: U1.16 (GPIO13)
DMXE1: J2.1, U1.17 (GPIO14)
DMXE2: J3.1, U1.18 (GPIO15)
DMXE3: J4.1, U1.34 (GPIO22)
DMXE4: U1.35 (GPIO23)
D_N: R4.1, U5.3 (I/O2)
D_P: R3.1, U5.1 (I/O1)
D_USB_N: J7.A7 (D-), J7.B7 (D-), U5.4 (I/O2)
D_USB_P: J7.A6 (D+), J7.B6 (D+), U5.6 (I/O1)
GND: C1.1, C2.2, C3.2, C4.2, C5.1, C6.2, C7.2, C8.2, C9.1, C10.1, C11.2, C12.2, C13.2, C14.2, C15.2, C16.2, C17.2, C18.2, C19.2, C20.2, C21.2, C22.2, C23.2, C24.2, D1.1 (K), J1.1, J7.A1 (GND), J7.A12 (GND), J7.B1 (GND), J7.B12 (GND), J7.S1 (SHIELD), J8.3, J9.8, J9.10, J9.11, R6.2, R7.2, R9.1, R10.1, R12.1, SW1.1, U1.19 (TESTEN), U1.57 (GND), U2.4 (GND), U3.1 (GND), U4.3 (AGND), U4.9 (AGND), U4.14 (AGND), U4.16 (AGND), U4.19 (AGND), U4.29 (GND), U4.48 (AGND), U5.2 (GND), Y1.2, Y1.4
INT: U1.32 (GPIO21), U4.36 (~INT)
LINKLED: J9.9, R13.2
MISO: U1.27 (GPIO16), U4.34 (MISO)
MOSI: U1.30 (GPIO19), U4.35 (MOSI)
unnamed: C15.1, FB1.2, J9.5
unnamed: C16.1, FB2.2, J9.4
unnamed: C20.1, J9.15 (SHIELD), J9.16 (SHIELD)
unnamed: D1.2 (A), R8.1
unnamed: J7.A4 (VBUS), J7.A9 (VBUS), J7.B4 (VBUS), J7.B9 (VBUS)
unnamed: R8.2, U1.6 (GPIO4)
unnamed: C7.1, U4.22 (1V2O)
unnamed: R14.1, U4.27 (ACTLED)
unnamed: R13.1, U4.25 (LINKLED)
unnamed: R12.2, U4.45 (PMODE0)
unnamed: R10.2, U4.44 (PMODE1)
unnamed: R9.2, U4.43 (PMODE2)
QSPI_CLK: U1.52 (QSPI_SCLK), U2.6 (CLK)
RST: U1.31 (GPIO20), U4.37 (~RST)
RX+: J9.3, U4.6 (RXP)
RX-: J9.6, U4.5 (RXN)
SCL: J6.1, R1.2, U1.12 (GPIO9)
SCLK: U1.29 (GPIO18), U4.33 (SCLK)
SCS: U1.28 (GPIO17), U4.32 (~SCS)
SD0: U1.53 (QSPI_SD0), U2.5 (DI(IO0))
SD1: U1.55 (QSPI_SD1), U2.2 (DO(IO1))
SD2: U1.54 (QSPI_SD2), U2.3 (IO2)
SD3: U1.51 (QSPI_SD3), U2.7 (IO3)
SDA: J6.2, R5.2, U1.11 (GPIO8)
SURFACERX: J5.2, U1.2 (GPIO0)
SURFACETX: J5.1, U1.3 (GPIO1)
SWCLK: J8.5, U1.24 (SWCLK)
SWD: J8.4, U1.25 (SWDIO)
TX+: J9.1, U4.2 (TXP)
TX-: J9.2, U4.1 (TXN)
XTAL_IN: C9.2, U1.20 (XTAL_IN), Y1.3
XTAL_OUT: R15.2, U1.21 (XTAL_OUT)
~RESET: J8.1, R2.2, U1.26 (~RUN)

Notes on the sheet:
MOUNTINGHOLES (REMOVED)
Maybe add something on shield?

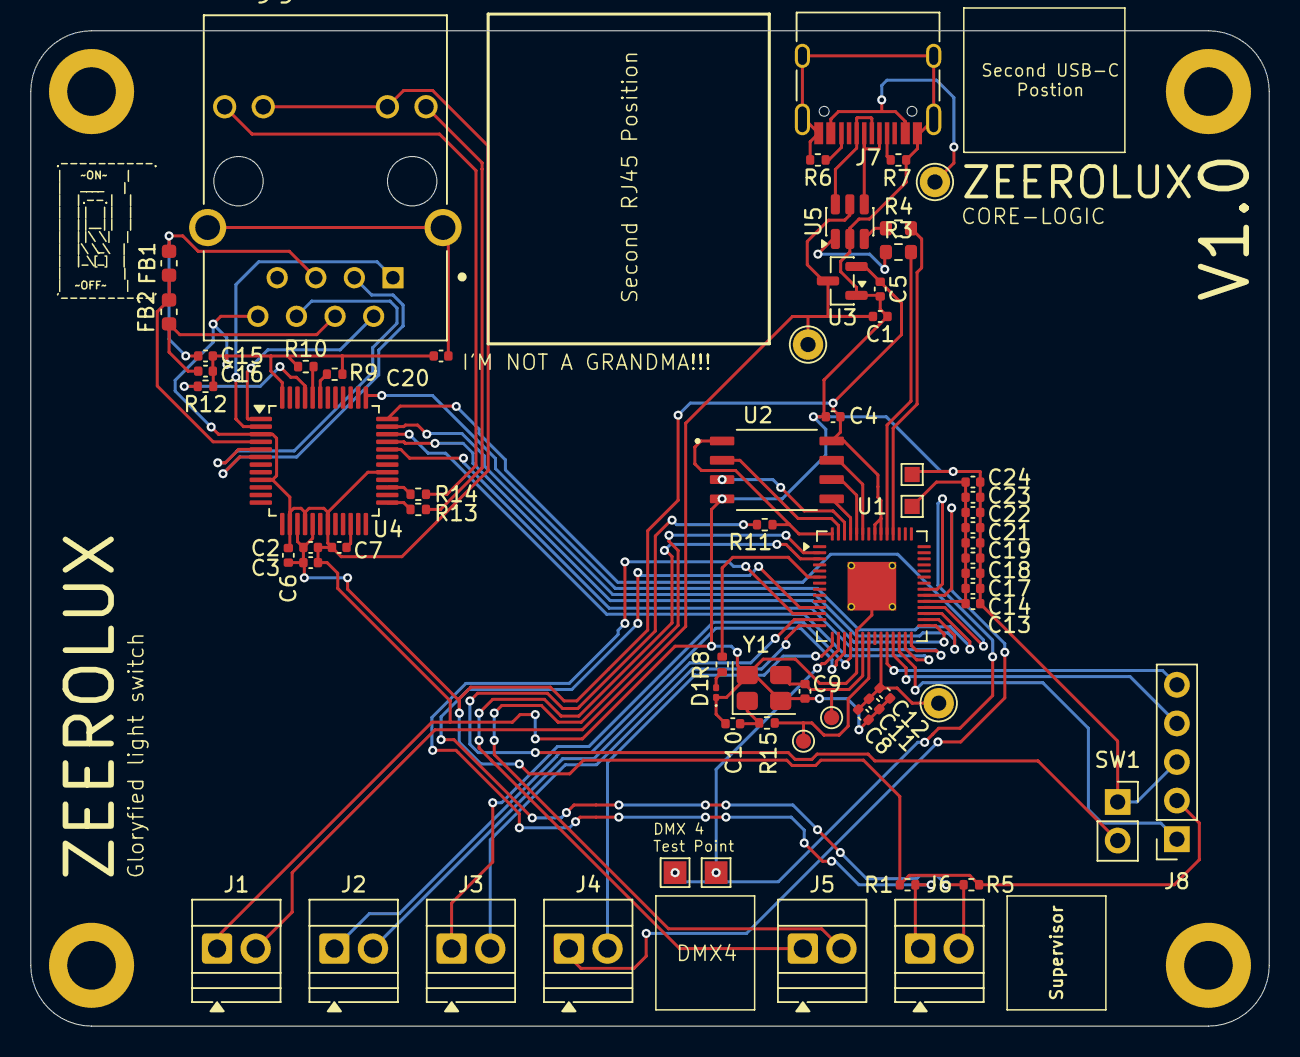
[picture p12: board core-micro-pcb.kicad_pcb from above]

Board: 2 copper layers, 81.5 x 65.5 mm, 57 parts (0 on the bottom side), 59 nets.

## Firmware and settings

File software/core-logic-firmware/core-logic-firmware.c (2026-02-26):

#include <stdio.h>
#include "pico/stdlib.h"
#include "hardware/pio.h"
#include "hardware/clocks.h"
#include "dmx_tx.pio.h"

#define DMX_PIN        2
#define DMX_CHANNELS   512
#define DMX_BAUD       250000

#define DMX_BREAK_US   100
#define DMX_MAB_US     12

PIO dmx_pio = pio0;
uint dmx_sm = 0;
uint dmx_offset;

uint8_t dmx_buffer[DMX_CHANNELS + 1];

void dmx_pio_init() {

    dmx_offset = pio_add_program(dmx_pio, &dmx_tx_program);

    pio_sm_config c = dmx_tx_program_get_default_config(dmx_offset);

    // Map output pin
    sm_config_set_out_pins(&c, DMX_PIN, 1);
    sm_config_set_sideset_pins(&c, DMX_PIN);

    // Shift out LSB first, autopull at 8 bits
    sm_config_set_out_shift(&c, true, true, 8);

    // 4 cycles per bit
    float div = (float)clock_get_hz(clk_sys) / (DMX_BAUD * 4);
    sm_config_set_clkdiv(&c, div);

    pio_gpio_init(dmx_pio, DMX_PIN);
    pio_sm_set_consecutive_pindirs(dmx_pio, dmx_sm, DMX_PIN, 1, true);

    pio_sm_init(dmx_pio, dmx_sm, dmx_offset, &c);
    pio_sm_set_enabled(dmx_pio, dmx_sm, true);

    dmx_buffer[0] = 0x00;  // Start code
}

void dmx_send_frame() {

    // Disable state machine so we can drive line manually
    pio_sm_set_enabled(dmx_pio, dmx_sm, false);

    gpio_set_function(DMX_PIN, GPIO_FUNC_SIO);
    gpio_set_dir(DMX_PIN, GPIO_OUT);

    // BREAK
    gpio_put(DMX_PIN, 0);
    sleep_us(DMX_BREAK_US);

    // MAB
    gpio_put(DMX_PIN, 1);
    sleep_us(DMX_MAB_US);

    // Return control to PIO
    gpio_set_function(DMX_PIN, GPIO_FUNC_PIO0);
    pio_sm_set_enabled(dmx_pio, dmx_sm, true);

    // Send 513 bytes
    for (int i = 0; i < DMX_CHANNELS + 1; i++) {
        pio_sm_put_blocking(dmx_pio, dmx_sm, dmx_buffer[i]);
    }
}

int main() {

    stdio_init_all();
    sleep_ms(1000);

    printf("PIO DMX Transmitter Starting...\n");

    dmx_pio_init();

    uint8_t level = 0;

    while (true) {

        // Simple ramp pattern
        for (int i = 1; i <= DMX_CHANNELS; i++) {
            dmx_buffer[i] = level;
        }

        dmx_send_frame();

        level++;
        sleep_ms(25);   // ~40 FPS
    }
}

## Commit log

2026-01-11 Add core-dmx KiCad project and backup files
    Added new core-dmx KiCad PCB, schematic, project, and related files, as well as backup archives. Also updated core-micro-pcb project files and added new backup and footprint cache files.
    [core-dmx.kicad_pcb, core-dmx.kicad_sch, core-micro-pcb.kicad_sch]
2026-01-23 power pcb added
    [core-micro-pcb.kicad_sch, core-power.kicad_pcb, core-power.kicad_sch]
2026-02-26 added cad
    [Base.3mf, Base.f3d, Top.3mf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]
2026-02-26 Various things were completed
    [core-dmx.kicad_pcb, core-dmx.step, core-micro-pcb.kicad_pcb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]
2026-02-26 moved stuff around and updated readme
    [core-dmx.kicad_pcb, core-dmx.kicad_sch, core-dmx.step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]
2026-02-26 Update README with PCB module details
    Expanded descriptions for each PCB module, detailing their functions and features.
2026-02-27 Add Bill of Materials section to README
    Added a Bill of Materials (BOM) section with item details, quantities, suppliers, and pricing.
2026-02-27 Refine BOM table headers in README.md
    Updated BOM table formatting for clarity.
2026-02-28 added bom
    [BOM.csv, BOM.xlsx, BOM_core-micro-surface.csv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]
2026-03-01 masde schematic look nicer
    [core-micro-pcb.kicad_sch]
